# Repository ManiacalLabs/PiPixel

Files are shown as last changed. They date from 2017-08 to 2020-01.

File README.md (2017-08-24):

If you require support, please post to the [Maniacal Labs Google Group](https://github.com/ManiacalLabs/PiPixel/blob/master/Usage.md#data-output-options).

# Maniacal Labs PiPixel

The PiPixel provides simplified hookup of digital LED strips to the Raspberry Pi family of single board computers. It uses the standard Pi "HAT" form-factor to provide two easy power input options, and data output of the SPI port as well as GPIO 18 and 13 (used for WS2812), along with built-in voltage level shifting to keep your LED strips happy being connected to the 3.3V Pi. No longer will you have a rats-nest of wires and power between your Pi and your LEDs. Slap on the PiPixel, connect power, connect LEDs, and go!

PiPixel Assembly & Usage (http://www.youtube.com/watch?v=wtbaeGrnpRE)

# What's In The Bag

Your PiPixel is a user assembled kit which only requires basic soldering skills and comes with the following components:

- PiPixel PCB
- Female 2x20 Header for connection to Pi
- 2.1 / 5.5 mm barrel jack for power input option #1
- 5mm pitch dual screw terminal for power input option #2
- 74AHCT125 Level Shifter
- 4 pin screw terminal for data/power output
- 2x3 pin header and jumper for data line selection

# Where To Get Optional Headers

We ship the PiPixel with a standard 2x20 Female header as that's what most users are likely to use. But it supports a few other options which we don't currently provide. See the list below for links of where to buy those, should you need them.

- [Extra Tall Female Header](https://www.sparkfun.com/products/14017)
- [Male Header](https://www.sparkfun.com/products/14275)
- [Stacking Header](https://www.adafruit.com/product/1979)
- [Ribbon Cable](https://www.sparkfun.com/products/13028)

# Assembly

Check out the full [Assembly doc](Assembly.md)

# Usage

For all the details on using your PiPixel, check out the [Usage doc](Usage.md)

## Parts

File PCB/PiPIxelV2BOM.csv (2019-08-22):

Designator | MPN | Qty | Link
J1 | PPPC202LFBN-RC | 1 | https://www.digikey.com/product-detail/en/sullins-connector-solutions/PPPC202LFBN-RC/S7123-ND/810259
J2 | 320120003 | 1 | https://statics3.seeedstudio.com/images/opl/datasheet/3410020P1.pdf
J3 | 320110031 | 1 | https://statics3.seeedstudio.com/images/opl/datasheet/3470110P1.pdf
J4 | 282834-4 | 1 | https://www.mouser.com/ProductDetail/282834-4
U1 | SN74AHCT125D | 1 | https://www.mouser.com/ProductDetail/595-SN74AHCT125D

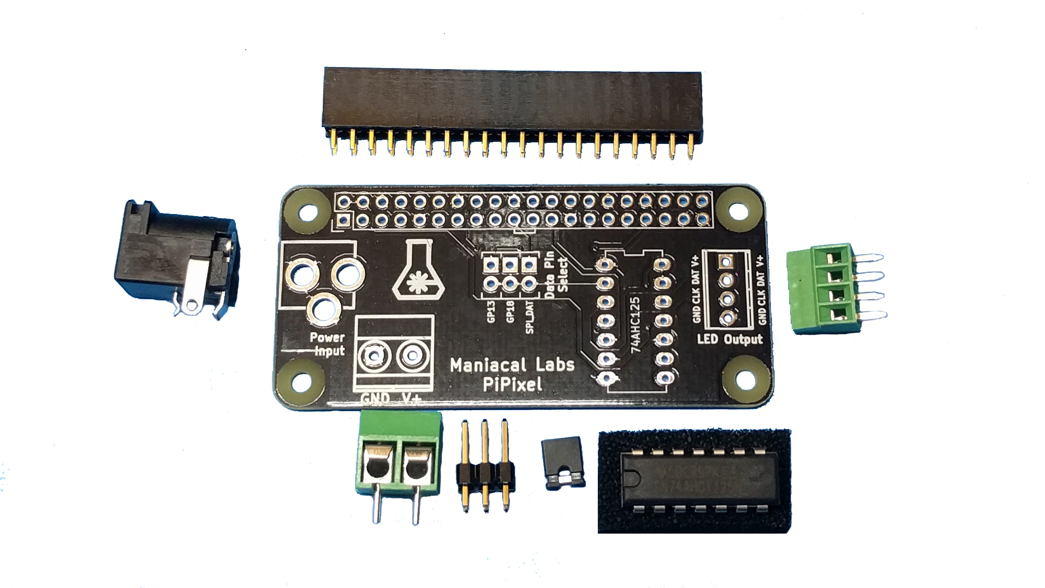
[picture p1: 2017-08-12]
img/Kit_Parts.jpg

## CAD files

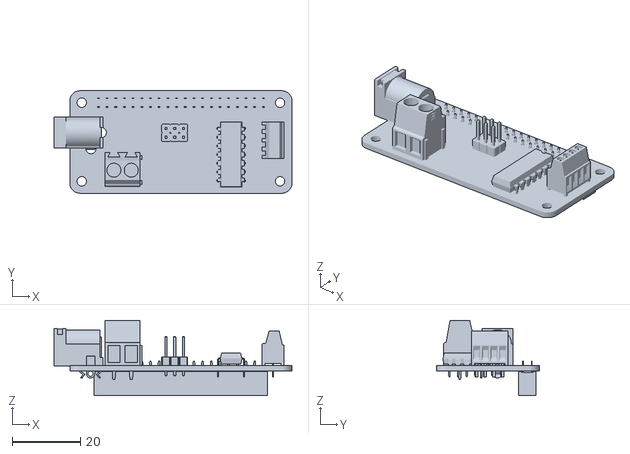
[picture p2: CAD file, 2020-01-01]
CAD/PiPixel_v1.stl
69.6 x 30.0 x 22.0

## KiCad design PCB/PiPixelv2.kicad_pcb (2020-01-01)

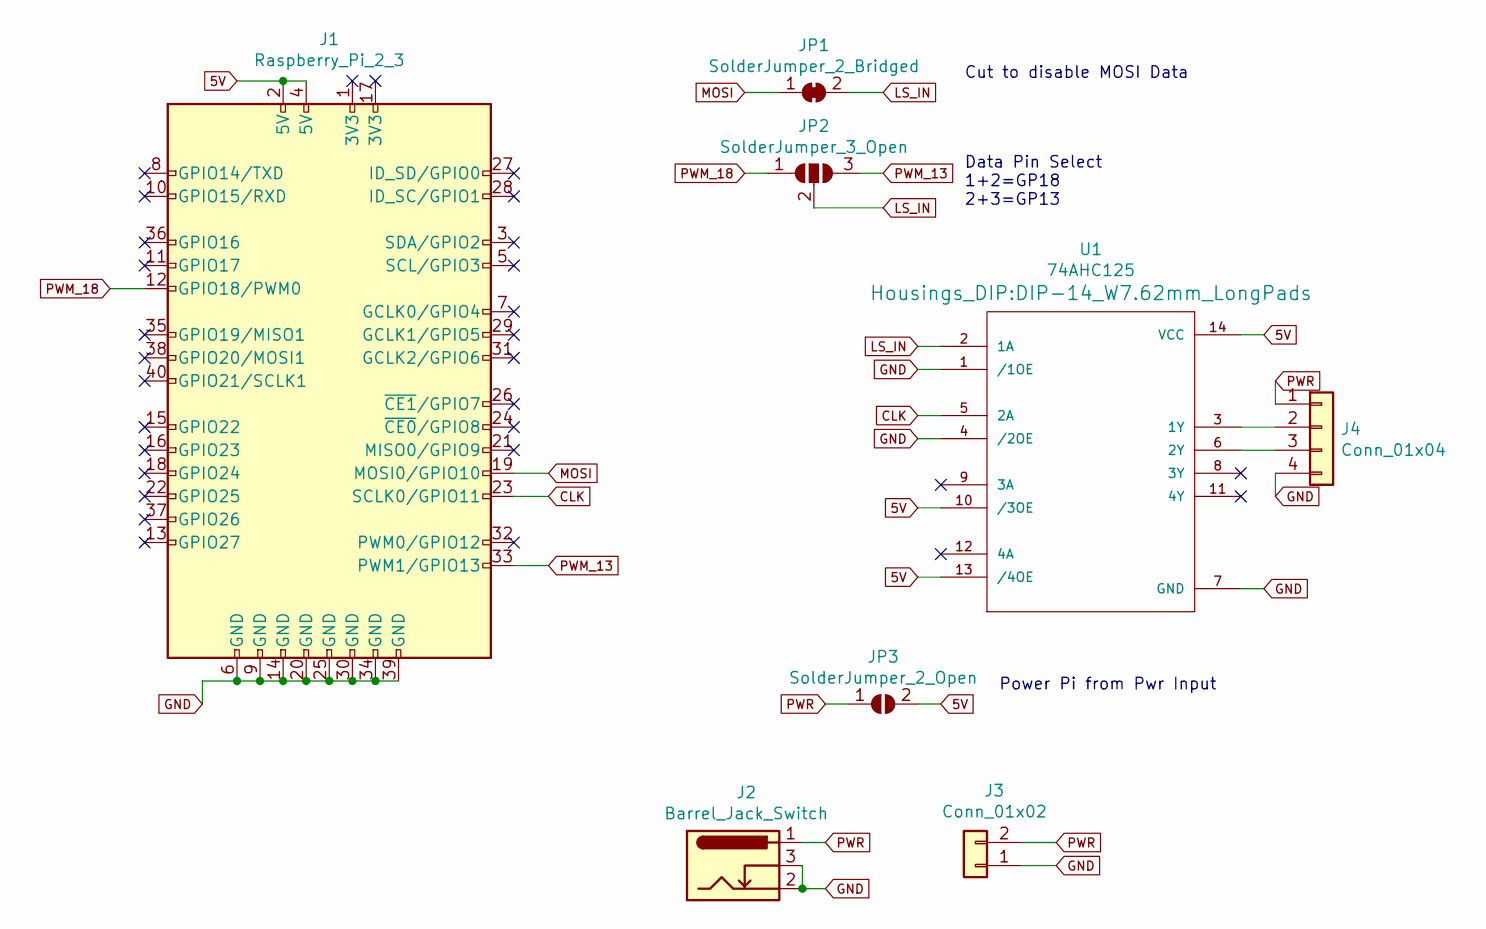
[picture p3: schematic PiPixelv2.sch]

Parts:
J1: Raspberry_Pi_2_3; Pin_Header_Straight_2x20_Pitch2.54mm
J2: Barrel_Jack_Switch; ML_BARREL_JACK_ROUND_PADS_SHORT
J3: Conn_01x02; mkds_1,5-2
J4: Conn_01x04; mpt_0,5%2f4-2,54
JP1: SolderJumper_2_Bridged; SolderJumper-2_P1.3mm_Bridged_Pad1.0x1.5mm
JP2: SolderJumper_3_Open; SolderJumper-3_P1.3mm_Open_Pad1.0x1.5mm_NumberLabels
JP3: SolderJumper_2_Open; SolderJumper-2_P1.3mm_Open_Pad1.0x1.5mm
U1: 74AHC125; DIP-14_W7.62mm_LongPads

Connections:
5V: J1.2 (5V), J1.4 (5V), JP3.2 (B), U1.10 (/3OE), U1.13 (/4OE), U1.14 (VCC)
CLK: J1.23 (SCLK0/GPIO11), U1.5 (2A)
GND: J1.6 (GND), J1.9 (GND), J1.14 (GND), J1.20 (GND), J1.25 (GND), J1.30 (GND), J1.34 (GND), J1.39 (GND), J2.2, J2.3, J3.1, J4.4, U1.1 (/1OE), U1.4 (/2OE), U1.7 (GND)
LS_IN: JP1.2 (B), JP2.2 (C), U1.2 (1A)
MOSI: J1.19 (MOSI0/GPIO10), JP1.1 (A)
unnamed: J4.2, U1.3 (1Y)
unnamed: J4.3, U1.6 (2Y)
PWM_13: J1.33 (PWM1/GPIO13), JP2.3 (B)
PWM_18: J1.12 (GPIO18/PWM0), JP2.1 (A)
PWR: J2.1, J3.2, J4.1, JP3.1 (A)

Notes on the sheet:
Cut to disable MOSI Data
Data Pin Select 1+2=GP18 2+3=GP13
Power Pi from Pwr Input

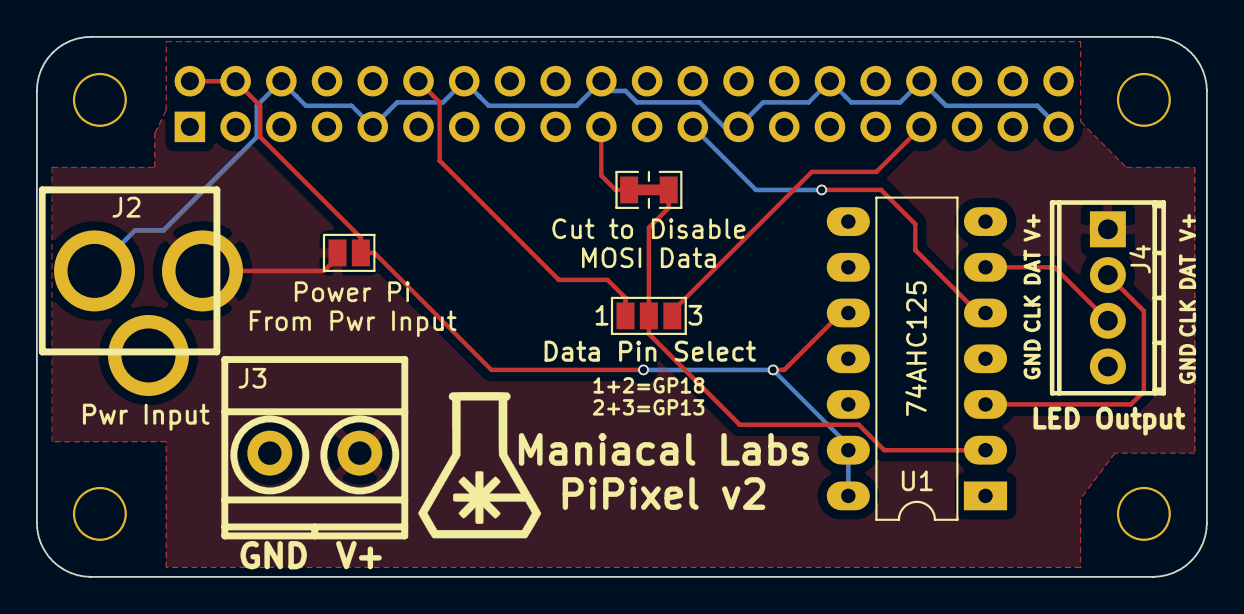
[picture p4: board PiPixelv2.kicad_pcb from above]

Board: 2 copper layers, 65.0 x 30.0 mm, 12 parts (0 on the bottom side), 10 nets.

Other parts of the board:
H1, H1#2, H1#3, H1#4: 3mm_Mounting_Hole; NPTH_3mm_ID

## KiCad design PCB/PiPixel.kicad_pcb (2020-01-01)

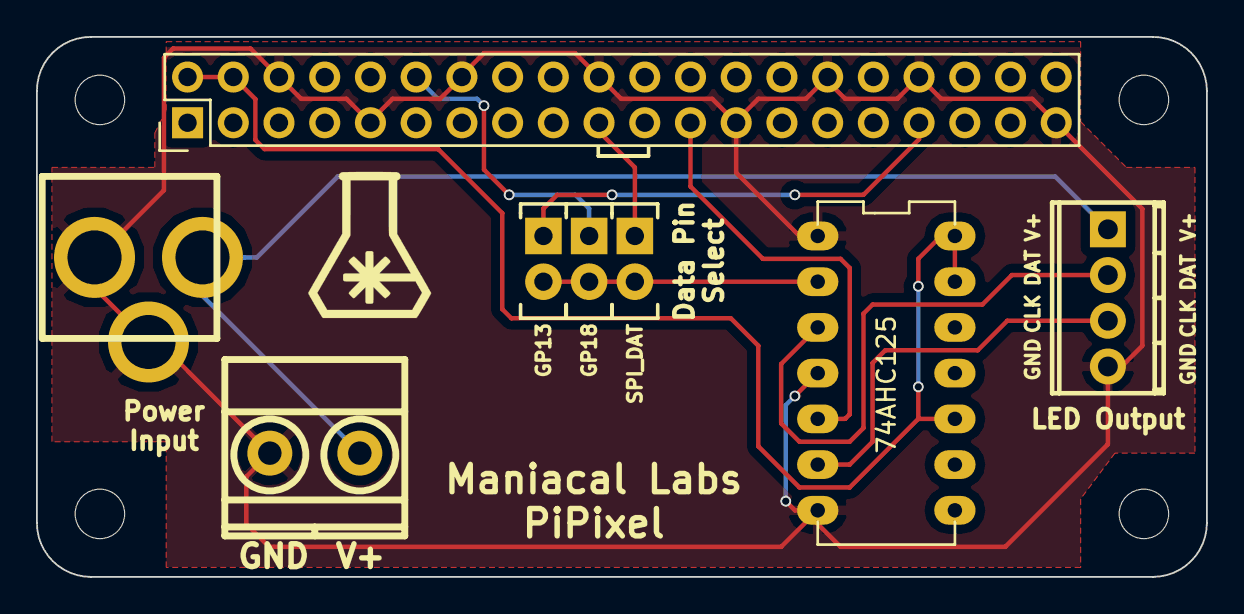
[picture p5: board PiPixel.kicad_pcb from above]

Board: 2 copper layers, 65.0 x 30.0 mm, 8 parts (0 on the bottom side), 10 nets.

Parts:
CON1: BARREL_JACK; ML_BARREL_JACK_ROUND_PADS_SHORT
J1: RPi_GPIO; Pin_Header_Straight_2x20
JP1: Jumper_NC_Small; small_jump
JP2, JP3: Jumper_NO_Small; small_jump
P1: CONN_01X04; mpt_0,5%2f4-2,54
P2: CONN_01X02; mkds_1,5-2
U1: 74AHC125; DIP_14

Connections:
5V: J1.2, J1.4, U1.10, U1.13, U1.14
CLK: J1.23, U1.5
GND: CON1.2, CON1.3, J1.6, J1.9, J1.14, J1.20, J1.25, J1.30, J1.34, J1.39, P1.4, P2.1, U1.1, U1.4, U1.7
MOSI: J1.19, JP1.1
unnamed: JP1.2, JP2.2, JP3.2, U1.2
unnamed: P1.2, U1.3
unnamed: P1.3, U1.6
PWM_13: J1.33, JP3.1
PWM_18: J1.12, JP2.1
PWR: CON1.1, P1.1, P2.2

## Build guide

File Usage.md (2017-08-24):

# PiPixel Usage

The following documentation will focus on usage of the PiPixel with [BiblioPixel](http://maniacallabs.com/BiblioPixel) but note that it simply provides power input and a level shifter for SPI, GPIO 13, or GPIO 18. So it could easily be used for anything that requires one of those 3 outputs.

As of writing this, the PiPixel is supported on the Pi A+, B+, 2, 3, Zero, and Zero W. As the original Pi has a smaller GPIO header the PiPixel does not support the original Pi.

Also be sure to checkout the PiPixel Assembly and Usage video:

PiPixel Assembly & Usage (http://www.youtube.com/watch?v=wtbaeGrnpRE)

### Power

The PiPixel has two input options, a black 2.1mm barrel jack and green 2-pin screw terminal. For both the maximum current is 5A. If you need more power, you will need to splice power into the LED strip further down the line.

The barrel jack is a standard 2.1 / 5.5 mm, positive tip type so make sure that you have the correct connector type with proper polarity.

The screw terminal is marked with GND and V+ so be sure to connect the correct polarity input to that connector.

Note that while most LED strips are 5V, the PiPixel supports any voltage input from 3v to 24v. Because the PiPixel does not power the connected Raspberry Pi directly, the input voltage is completely separated from the Pi and high voltages will not damage it. Just be sure to use the correct voltage for your LEDs!

### Data Output Options

The PiPixel has 3 options for data output, to support a variety LED strip types. To select which option you would like to use, move the provided jumper to one of the following locations on the data selection header:

- SPI_DAT: For SPI data output, using `/dev/spi0.0`. Use with any SPI-type LED strip such as APA102 (DotStar), SK9822, LPD8806 or WS2801. All of these are supported directly by BiblioPixel.
- GP18: GPIO #18 and the default option for use with WS2812 (NeoPixel) LEDs via the  [PiWS281X](https://github.com/ManiacalLabs/BiblioPixel/wiki/PiWS281X) BiblioPixel driver.
- GP13: A secondary option for WS2812 LEDs in case GPIO #18 is in use by something else. Be sure to change the `gpio` parameter to 13 in your PiWS281X configuration.

### LED Count Limits

If using [PiWS281X](https://github.com/ManiacalLabs/BiblioPixel/wiki/PiWS281X) there's no theoretical limit other than more pixels require more time to update per frame. But SPI is limited by the Raspbian OS to only 4096 bytes. However, you can increase the SPI buffer pretty easily:

This can be changed in /boot/cmdline.txt by appending

`spidev.bufsiz=32768`

The above will increase your pixel limit 8 times to over 10,000 pixels for LPD8806 and WS2801 and just over 8,000 for APA102 and SK9822.

### Running with BiblioPixel

First, follow the [BiblioPixel Installation instructions](https://github.com/ManiacalLabs/BiblioPixel/wiki/Installation).

We will focus only on using the BiblioPixel [Project](https://github.com/ManiacalLabs/BiblioPixel/wiki/Projects) functionality. For example, a simple configuration would be:

```
{
    "animation": {
        "typename": "BiblioPixelAnimations.strip.Rainbows.RainbowCycle"
    },
    "run": {
        "fps": 30
    },
    "driver": {
        "typename": "spi",
        "c_order": "RGB",
        "ledtype": "APA102",
        "num": 64
    },
    "layout": {
        "typename": "strip",
        "brightness": 128
    }
}
```

You can see this in action by calling:

```
bibliopixel run https://github.com/ManiacalLabs/PiPixel/blob/master/Demos/spi.json --ledtype APA102
```

Note the `--ledtype` option given in this case. The `spi.json` file linked to above leaves out the `"ledtype": "APA102"` option in the `driver` section so that you can choose your `ledtype` when running. It was done this way so that the demo could work for any user with any type of LEDs. Valid `ledtype` options when using `SPI_DAT` are:
- APA102
- SK9822
- WS2801
- LPD8806

I avoid the need for the `--ledtype` option, you can simply hard-code it into the file as shown in the example above: `"ledtype": "APA102"` in the `driver` section.

If you would like to, instead, test with the WS2812 (NeoPixel) LEDs first switch the data select jumper to `GP18`, then call:

```
bibliopixel run https://github.com/ManiacalLabs/PiPixel/blob/master/Demos/ws2812.json
```

As this uses the `PiWS281X` driver instead of `SPI`, no `--ledtype` option is required. If you would like to instead use GPIO 13, download the file and change `gpio` to 13, switch the select jumper to `GP13` then run the command again against the local file.

That's really all there is to it in terms of specifics of PiPixel and BiblioPixel. Checkout the [BiblioPixel Wiki](https://github.com/ManiacalLabs/BiblioPixel/wiki) for more details on its usage.

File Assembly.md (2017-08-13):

## PiPixel Assembly

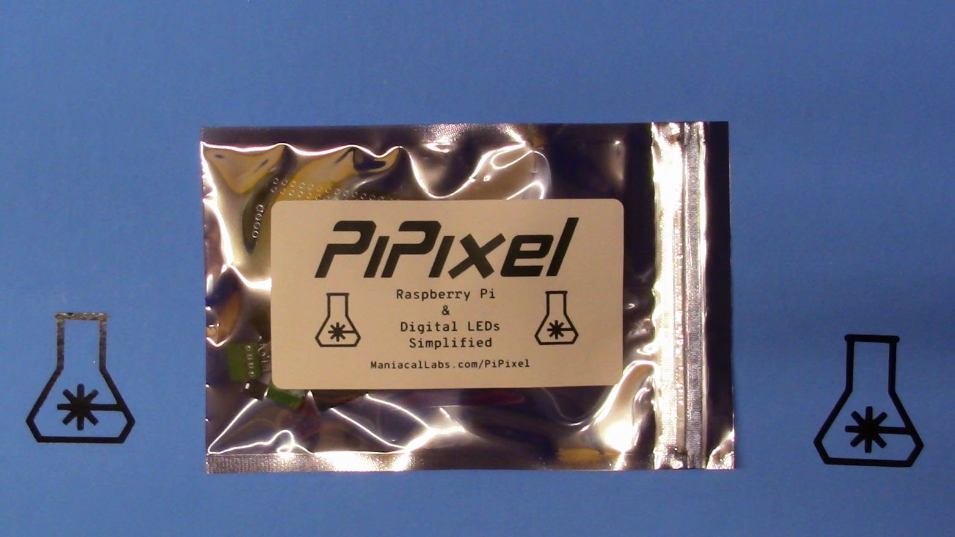
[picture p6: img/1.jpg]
Kit Package


The PiPixel is a simple kit with minimal parts and only requires basic soldering skills. You can either follow along with the instructions in this document or follow the build process in the video below:

PiPixel Assembly & Usage (http://www.youtube.com/watch?v=wtbaeGrnpRE)

#### Kit Contents
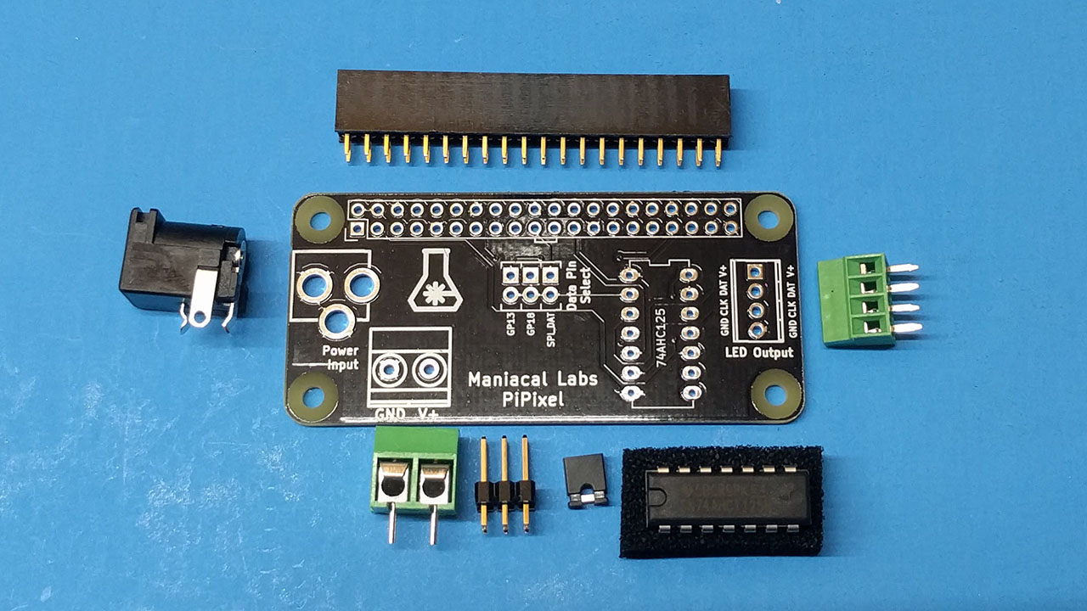
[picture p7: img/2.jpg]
Kit Parts


Your PiPixel kit should contain the following items, as shown above:
- PiPixel PCB
- Female 2x20 Header for connection to Pi
- 2.1 / 5.5 mm barrel jack for power input option #1
- 5mm pitch dual screw terminal for power input option #2
- 74AHCT125 Level Shifter
- 4 pin screw terminal for data/power output
- 2x3 pin header and jumper for data line selection

#### Female Header

*Note: You may also want to use a male header or pass-through header, depending on your situation. But as most will need the female header that is what he provide. See the main [README](README.md) for links to other header options.*

First, we recommend placing the PCB with the header inserted onto your work surface, and soldering just a single pin. Now that the header will stay on, hold the PCB and provide pressure to the back of the header while re-heating the one solder joint. You can now ensure the header is properly aligned and hold it in place while the solder cools.
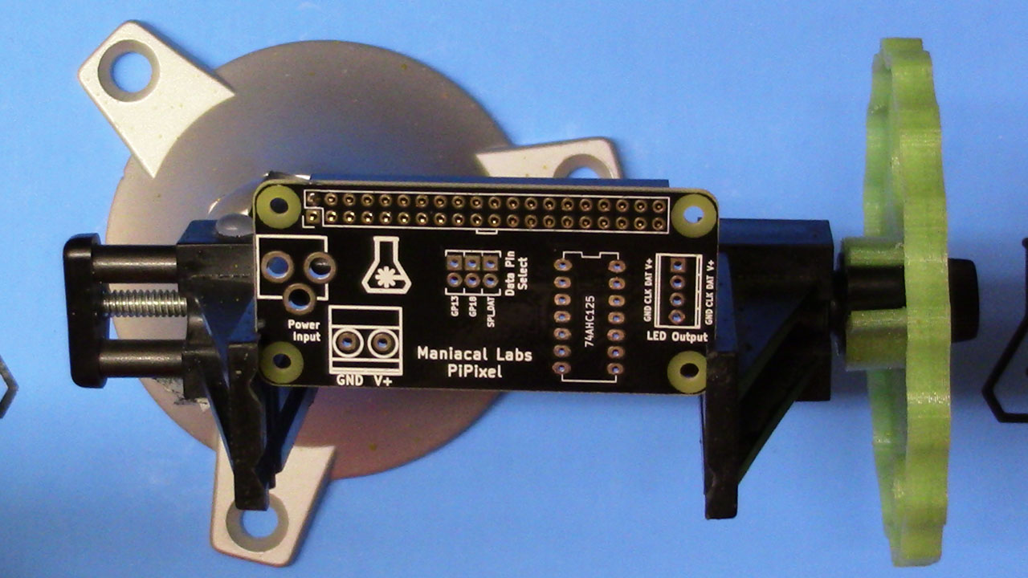
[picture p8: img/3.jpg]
Header 1


Next, solder the remainder of the header pins.

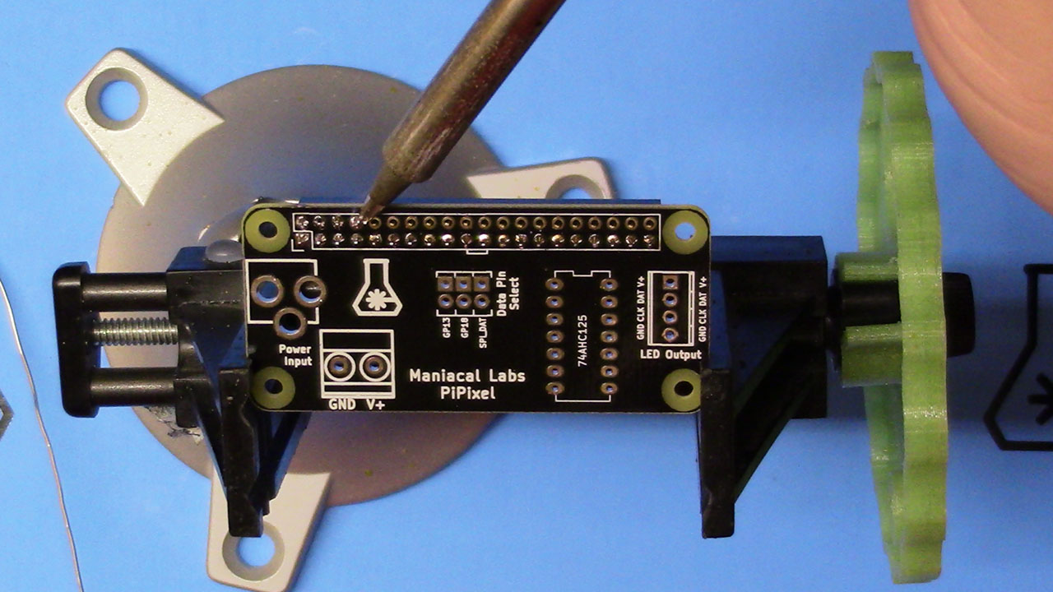
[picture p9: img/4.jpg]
Header 2


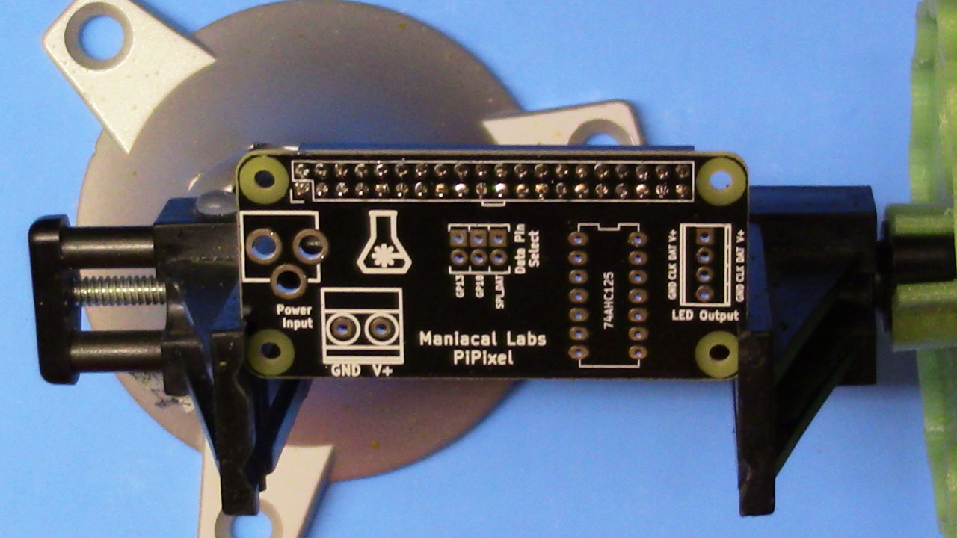
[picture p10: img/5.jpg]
Header 3


#### Barrel Jack

Insert the barrel jack, then flip over the PCB. Apply a small amount of solder to a single pin. Then now use your free hand (which is no longer holding solder) to, like with the female header, apply a little pressure while re-heating the solder to ensure the jack is properly aligned.

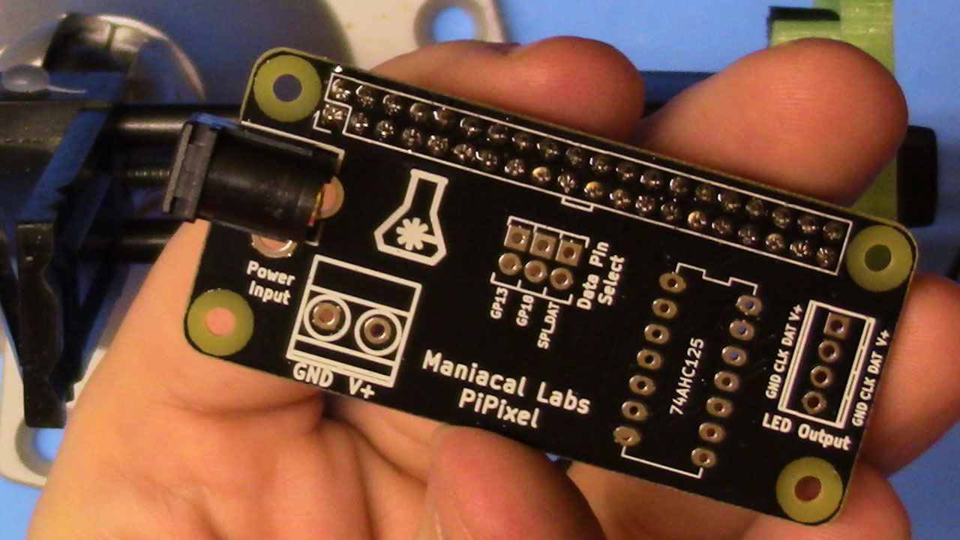
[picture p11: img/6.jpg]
Barrel Jack


Then solder the other two barrel jack pins, taking your time to ensure the holes are completely filled with solder. Then go back to the first pin and add the remaining solder to fill the hole.

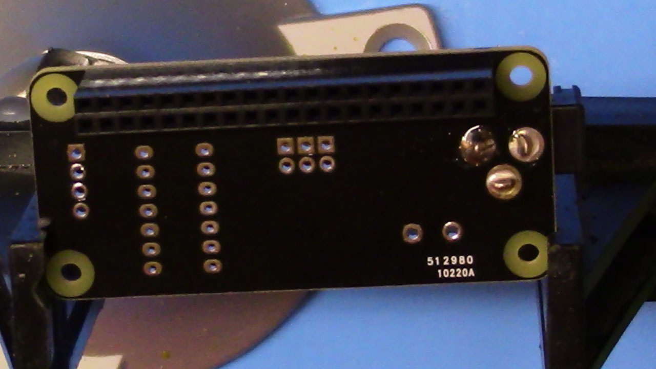
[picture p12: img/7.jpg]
Barrel Jack Solder


#### Power Screw Terminal & Data jumper

Insert the power screw terminal (ensure the holes face outward!) and the 2x3 jumper header.

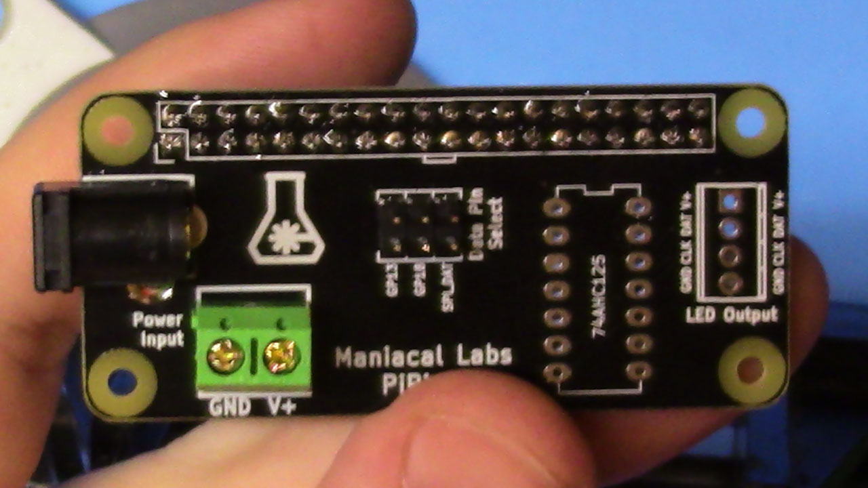
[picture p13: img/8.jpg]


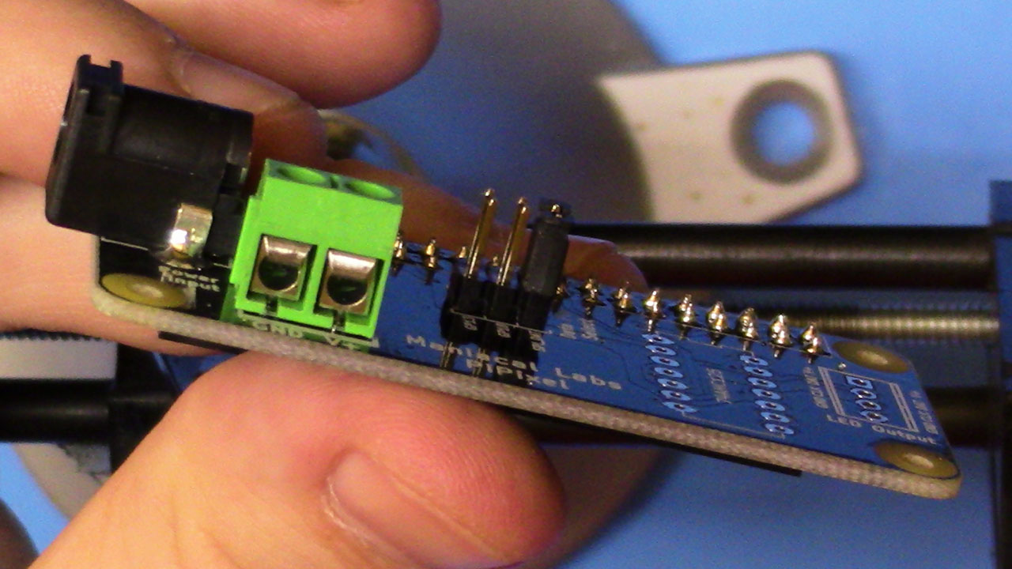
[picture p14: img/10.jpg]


Flip the PCB and solder the screw terminal pins and the jumper header pins. Like with previous parts, ensure that the components are aligned correctly before soldering all pins.

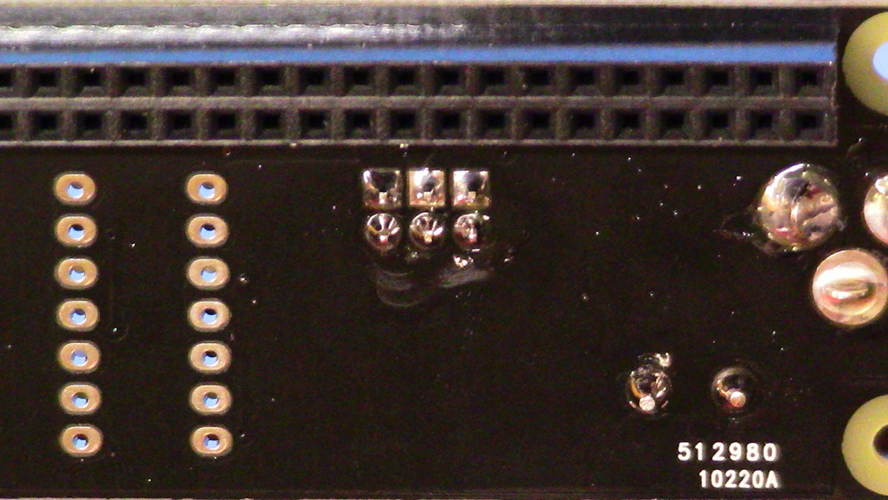
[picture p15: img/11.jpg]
Header & Power 2 Solder


#### 74AHCT125 Level Shifter

**_IMPORTANT!_**: The level shifter has a notch on one side and the PCB silkscreen shows a notch as well. Those notches *__must__* be aligned or the PiPixel will not work!

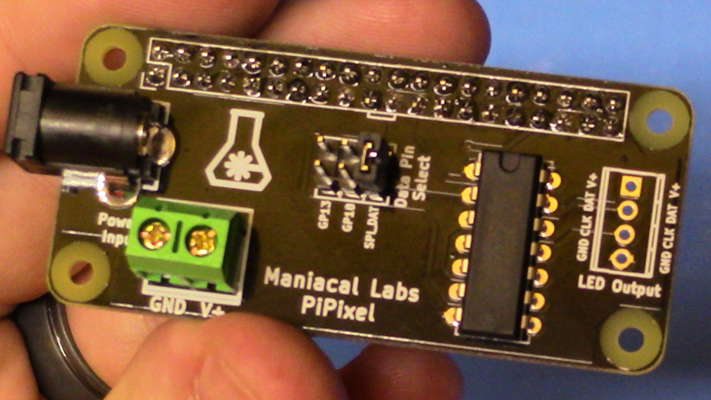
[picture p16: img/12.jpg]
Level Shifter


The pins on the level shifter will be angled outward and need to be bent in slightly to fit in the socker. Place each side of the IC against your work surface and gently press down to bend the pins slightly inward, so they look like below:

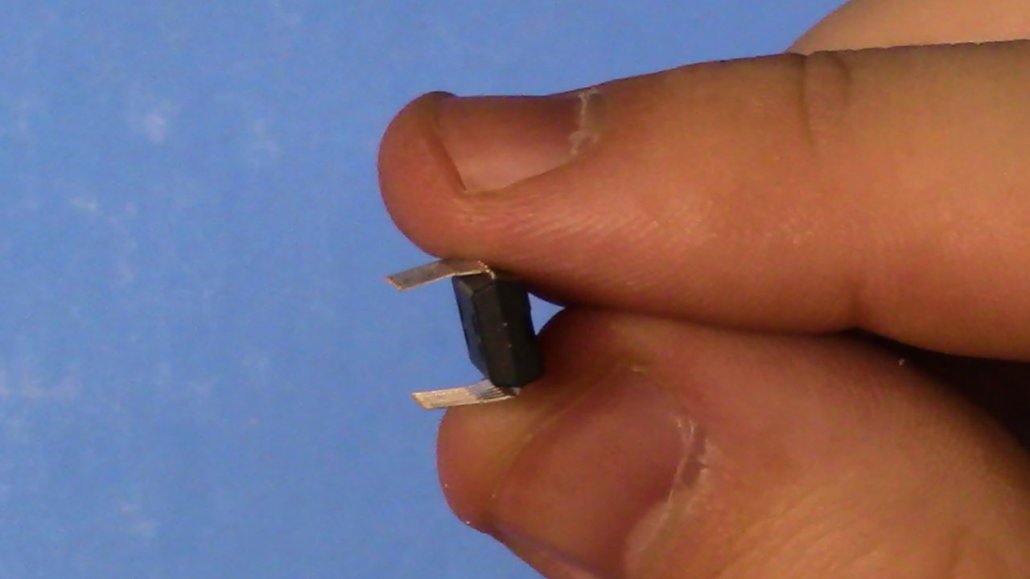
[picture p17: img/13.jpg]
Level Shifter Pins


Finally, insert the level shifter, noting the notch orientation, and solder all pins.

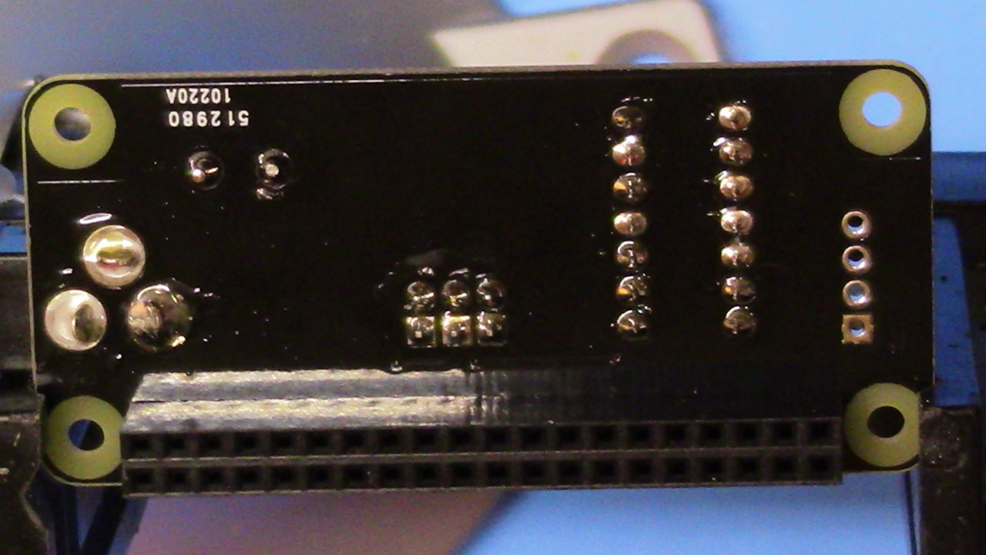
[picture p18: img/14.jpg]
Level Shifter Solder


#### 4-pin Screw Terminal

Insert the 4-pin data/power terminal, flip the PCB laying it flat on your work surface and solder one pin. Ensure it is aligned properly and reheat and fix if not.

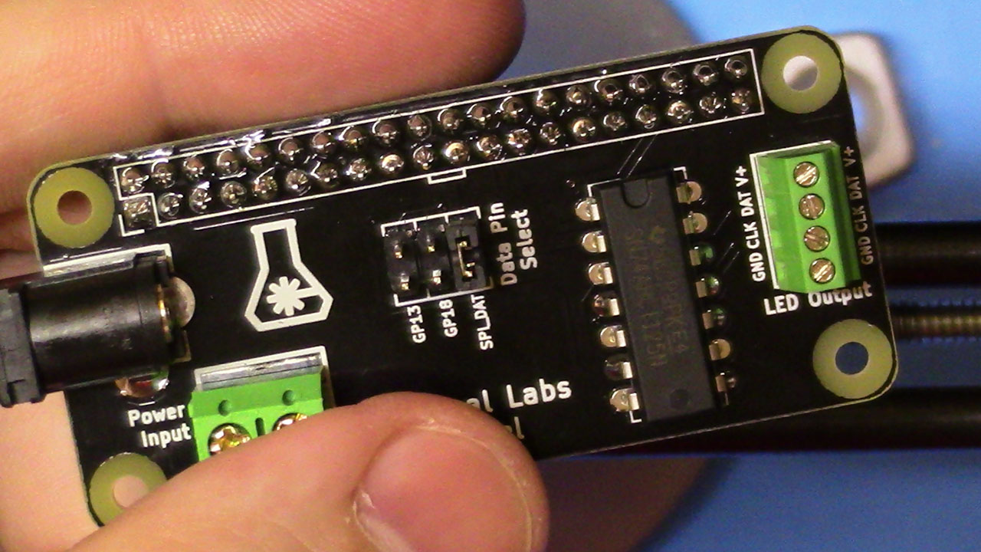
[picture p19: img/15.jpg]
Data/Power Out


The solder the remaining screw terminal pins.

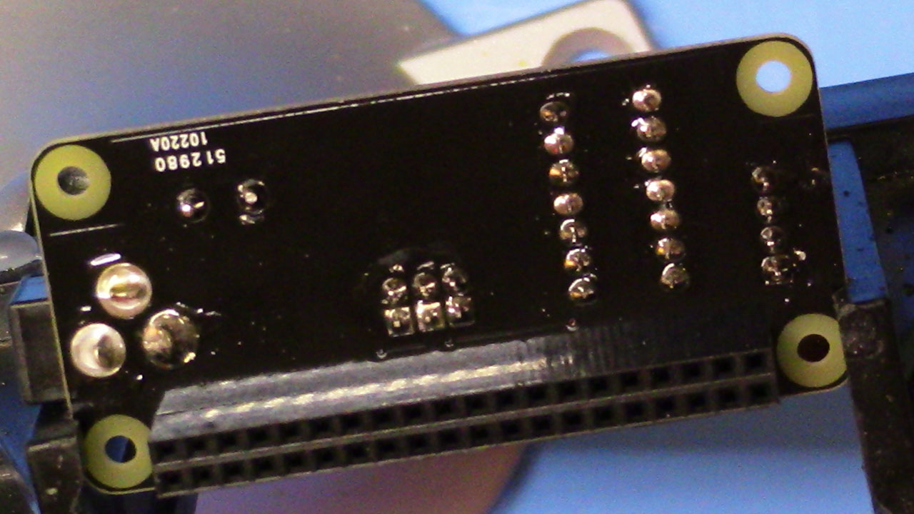
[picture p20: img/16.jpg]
Data/Power Out Solder


Congratulations, you're done!

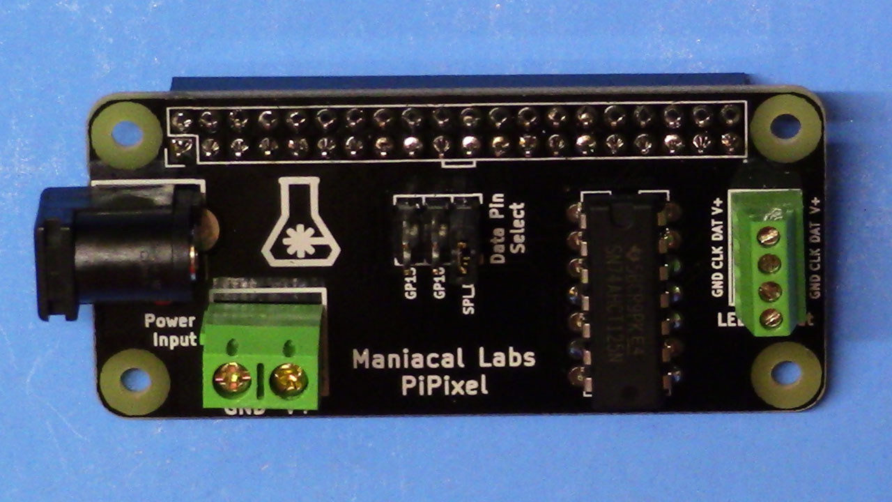
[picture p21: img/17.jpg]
Fully Assembled


For all the details on using the PiPixel, checkout the [Usage](Usage.md) doc.

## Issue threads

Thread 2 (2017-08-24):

Length limits?

drewcovi, 2017-08-24:
apologies as this is a bit of a n00b question: any limit on LED count? I know the AllPixel Mini drives north of 700.

adammhaile, 2017-08-24:
SPI is limited to 4096 bytes so it depends on the LED type and the rpi_ws281x interface has no limit other than speed.

Please post to https://groups.google.com/forum/#!forum/maniacal-labs-users in the future :) We will be closing down issues here and exclusively using that for support.

adammhaile, 2017-08-24:
See this for increasing the SPI limit: https://github.com/ManiacalLabs/PiPixel/blob/master/Usage.md#led-count-limits

ianmaddox, 2019-03-28:
What's the current limit across the Strip HAT? How many 50mA LEDs can I drive before this thing is overloaded?

adammhaile, 2019-03-28:
Power-wise, 5A if you use the attached barrel connector.
So 5000mA / 60mA = 83 leds. 60mA is typical max per pixel. In reality you can probably run ~300 if you don't do all white.

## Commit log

2017-06-18 Full layout
    [PiLEDStripHat.kicad_pcb, PiLEDStripHat.sch]
2017-07-02 fixed GPIO mappings
    [PiLEDStripHat-B.Cu.gbr, PiLEDStripHat-B.Mask.gbr, PiLEDStripHat-B.SilkS.gbr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]
2017-07-20 Updating gerbers
    [PiLEDStripHat-B.Cu.gbr, PiLEDStripHat-B.Mask.gbr, PiLEDStripHat-B.SilkS.gbr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]
2017-07-20 Added mask gerbers
    [PiLEDStripHat-B.Cu.gbr, PiLEDStripHat-B.Mask.gbr, PiLEDStripHat-B.SilkS.gbr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]
2017-08-12 Re-organize everything
    [PiLEDStripHat-B.Cu.gbr, PiLEDStripHat-B.SilkS.gbr, PiLEDStripHat-Cmts.User.gbr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]
2017-08-12 fix after merge
    [PiLEDStripHat-B.Mask.gbr, PiLEDStripHat-F.Mask.gbr]
2017-08-12 Assembly doc
2019-07-28 Initial Commit of PiPixelv2
    [PiPixel-2019-07-27-20-46-41.sch, PiPixelv2.kicad_pcb, PiPixelv2.sch]
2019-07-28 Further PCB changes, library adds
    [PiPixelv2.kicad_pcb]
2019-07-28 v2 PCB layout, traces complete.
    [PiPixelv2.kicad_pcb, PiPixelv2.sch]
2019-07-28 Made GND connections to top row of pins on Pi header, DRC Pass
    [PiPixelv2.kicad_pcb]
2019-08-20 Updated FSilk with RefDes for MFG
    [PiPixelv2.kicad_pcb]
2019-08-20 Generated gerber files for submission to Seeed for quote
    [PiPixelv2-B_Cu.gbr, PiPixelv2-B_Mask.gbr, PiPixelv2-B_SilkS.gbr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]
2019-08-22 Modified Pi Header to show on BSilk
    [PiPixelv2-B_Cu.gbr, PiPixelv2-B_Mask.gbr, PiPixelv2-B_SilkS.gbr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]
2019-08-22 Committing BOM file for PiPixelV2
    [PiPIxelV2BOM.csv]
2019-08-28 adding CAD models for v1
    [PiPixel.kicad_pcb, PiPixel_v1.stl]
2020-01-01 Changed v2 design to TH Level Shifter
    [PiPixelv2.kicad_pcb, PiPixelv2.sch]
